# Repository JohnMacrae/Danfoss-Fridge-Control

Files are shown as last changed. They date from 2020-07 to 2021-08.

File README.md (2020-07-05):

# Danfoss-Fridge-Control

I have a Danfoss BD35 and BD50 compressor running the fridge and freezer on my boat. This project has been brewing since I sopke with a friend, Rick, back in 2016 but although I tinkered with it, I didn't get serious - mostly due to lack of confidence born out of lack of competence :)
While we were on board in 2019, however, the mechanical thermostat on the fridge (BD35) broke and I was forced to 'create' something out of what was on board  - an ESP8266, a DS18b20 and a chinesium relay.

It was successful and ran for months without any problems but as you can see it was a bit of a bodge.  So, I decided to make a board and run it on an ESP32.

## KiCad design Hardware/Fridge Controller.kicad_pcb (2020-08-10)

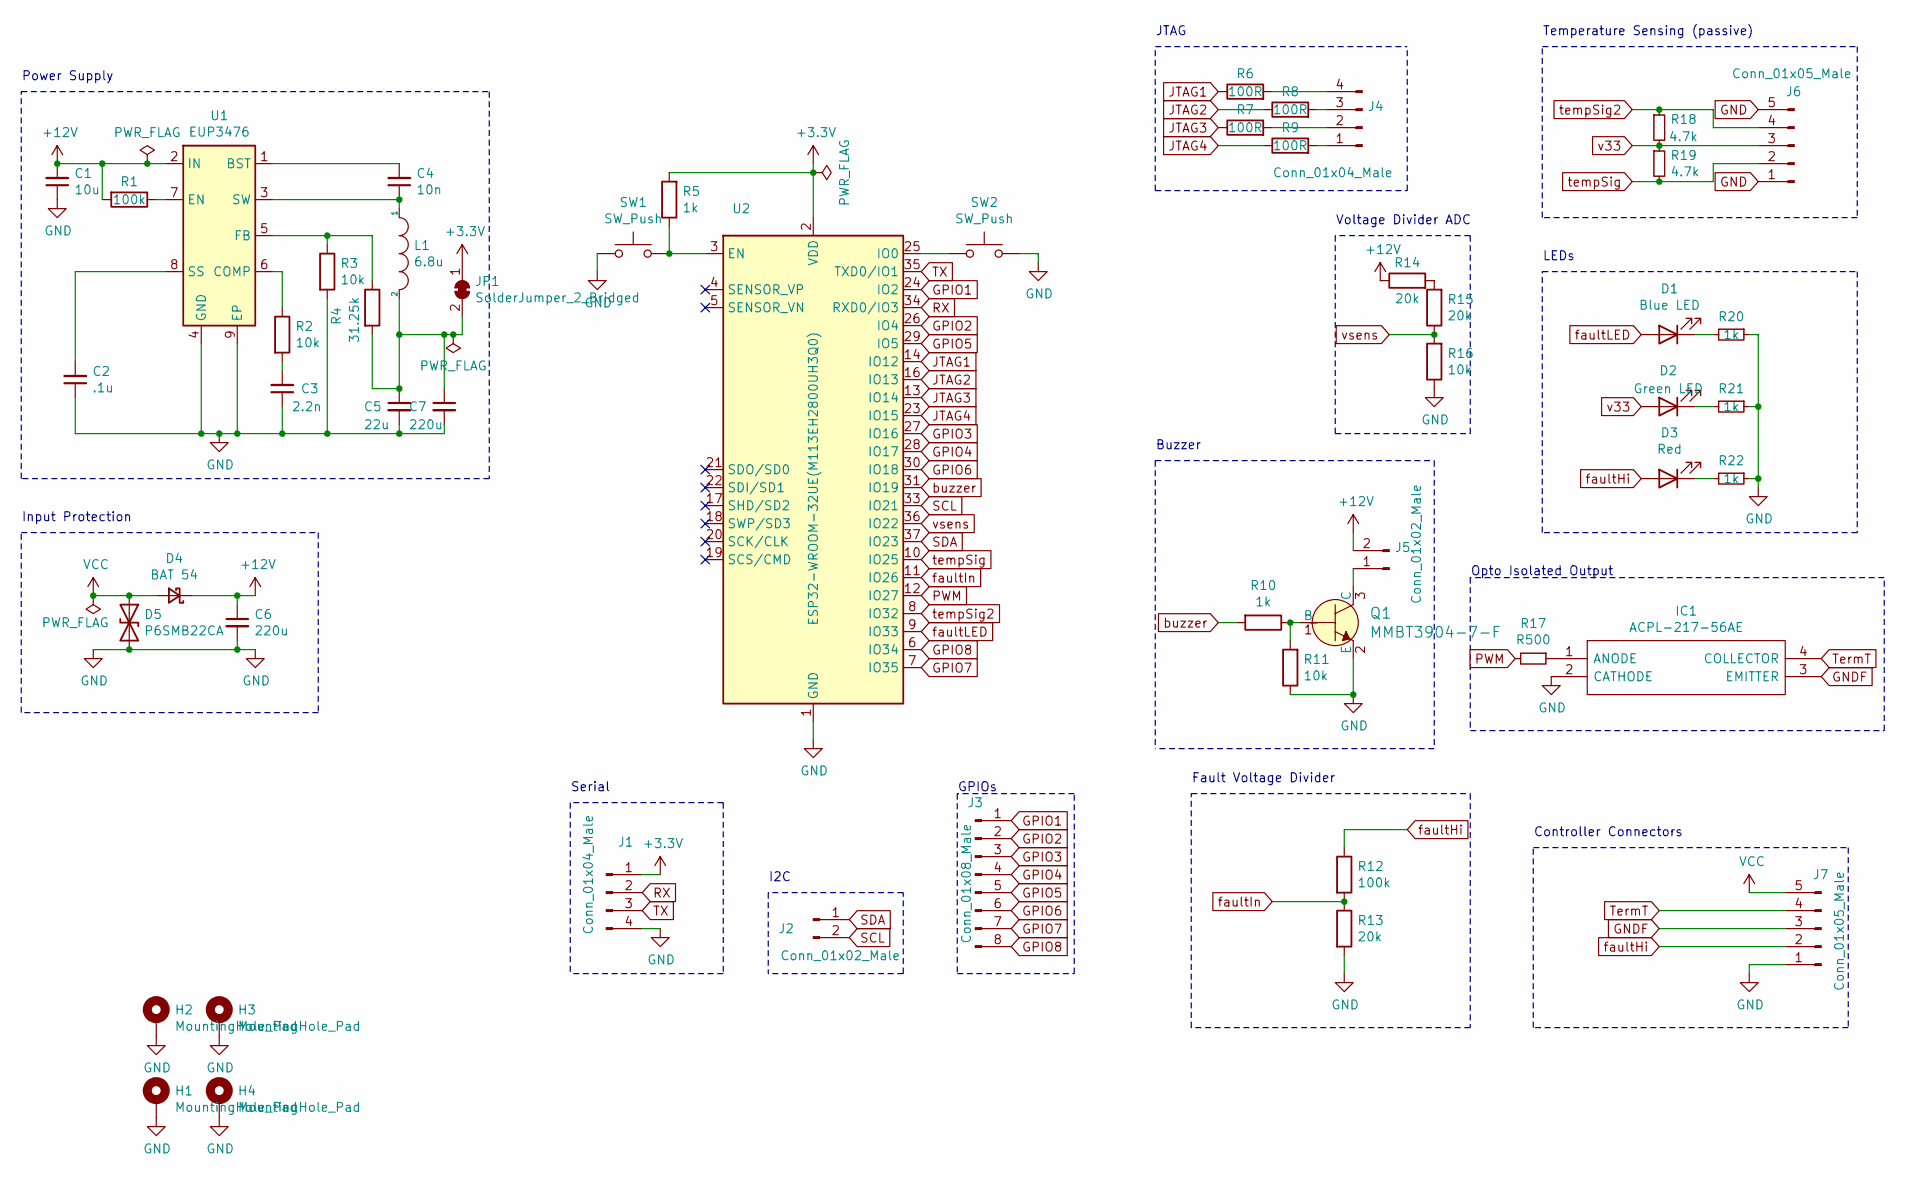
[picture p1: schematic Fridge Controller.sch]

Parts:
C1: 10u; C_0805_2012Metric_Pad1.15x1.40mm_HandSolder
C2: .1u; C_0805_2012Metric_Pad1.15x1.40mm_HandSolder
C3: 2.2n; C_0805_2012Metric_Pad1.15x1.40mm_HandSolder
C4: 10n; C_0805_2012Metric_Pad1.15x1.40mm_HandSolder
C5: 22u; C_0805_2012Metric_Pad1.15x1.40mm_HandSolder
C6: 220u; C_1206_3216Metric_Pad1.42x1.75mm_HandSolder
C7: 220u; CP_EIA-7343-31_Kemet-D_Pad2.25x2.55mm_HandSolder
D1: Blue LED; LED_1206_3216Metric
D2: Green LED; LED_1206_3216Metric
D3: Red; LED_1206_3216Metric
D4: BAT 54; D_SOT-23_ANK
D5: P6SMB22CA; D_SMB
H1, H2, H3, H4: MountingHole_Pad; MountingHole_3.2mm_M3_Pad_Via
IC1: ACPL-217-56AE; SOIC127P700X242-4N; Mouser Part Number 630-ACPL-217-56AE
J1, J4: Conn_01x04_Male; PinHeader_1x04_P2.54mm_Vertical
J2, J5: Conn_01x02_Male; PinHeader_1x02_P2.54mm_Vertical
J3: Conn_01x08_Male; PinHeader_1x08_P2.54mm_Vertical
J6, J7: Conn_01x05_Male; JST_XH_B5B-XH-A_1x05_P2.50mm_Vertical
JP1: SolderJumper_2_Bridged; SolderJumper-2_P1.3mm_Open_Pad1.0x1.5mm
L1: 6.8u; L_Abracon_ASPI-0630LR
Q1: MMBT3904-7-F; SOT-23-3; MPN MMBT3904-7-F; Digi-Key_PN MMBT3904-FDICT-ND
R1, R12: 100k; R_0805_2012Metric_Pad1.15x1.40mm_HandSolder
R2, R3, R11, R16: 10k; R_0805_2012Metric_Pad1.15x1.40mm_HandSolder
R4: 31.25k; R_0805_2012Metric_Pad1.15x1.40mm_HandSolder
R5, R10, R20, R21, R22: 1k; R_0805_2012Metric_Pad1.15x1.40mm_HandSolder
R6, R7, R8, R9: 100R; R_0805_2012Metric_Pad1.15x1.40mm_HandSolder
R13, R14, R15: 20k; R_0805_2012Metric_Pad1.15x1.40mm_HandSolder
R17: R500; R_0805_2012Metric_Pad1.15x1.40mm_HandSolder
R18, R19: 4.7k; R_0805_2012Metric_Pad1.15x1.40mm_HandSolder
SW1, SW2: SW_Push; SW_PUSH_6mm_H5mm
U1: EUP3476; HSOP-8-1EP_3.9x4.9mm_P1.27mm_EP2.41x3.1mm
U2: ESP32-WROOM-32UE(M113EH2800UH3Q0); ESP32-WROOM-32

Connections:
+3V3: J1.1, JP1.1 (A), R5.2, U2.2 (VDD)
+12V: C1.2, C6.1, D4.1 (K), J5.2, R1.2, R14.1, U1.2 (IN)
GND: C1.1, C2.1, C3.1, C5.2, C6.2, C7.2, D5.2 (A2), H1.1, H2.1, H3.1, H4.1, IC1.2 (CATHODE), J1.4, J6.1, J6.5, J7.1, Q1.2 (E), R3.2, R11.1, R13.2, R16.1, R20.1, R21.1, R22.1, SW1.1, SW2.2, U1.4 (GND), U1.9 (EP), U2.1 (GND), U2.15 (GND), U2.38 (GND), U2.39 (GND)
GNDF: IC1.3 (EMITTER), J7.3
GPIO1: J3.1, U2.24 (IO2)
GPIO2: J3.2, U2.26 (IO4)
GPIO3: J3.3, U2.27 (IO16)
GPIO4: J3.4, U2.28 (IO17)
GPIO5: J3.5, U2.29 (IO5)
GPIO6: J3.6, U2.30 (IO18)
GPIO7: J3.7, U2.7 (IO35)
GPIO8: J3.8, U2.6 (IO34)
JTAG1: R6.1, U2.14 (IO12)
JTAG2: R8.1, U2.16 (IO13)
JTAG3: R7.1, U2.13 (IO14)
JTAG4: R9.1, U2.23 (IO15)
unnamed: C2.2, U1.8 (SS)
unnamed: C3.2, R2.2
unnamed: C4.1, L1.1, U1.3 (SW)
unnamed: C4.2, U1.1 (BST)
unnamed: C5.1, C7.1, JP1.2 (B), L1.2, R4.2
unnamed: D1.1 (K), R20.2
unnamed: D2.1 (K), R21.2
unnamed: D3.1 (K), R22.2
unnamed: IC1.1 (ANODE), R17.1
unnamed: J4.1, R9.2
unnamed: J4.2, R7.2
unnamed: J4.3, R8.2
unnamed: J4.4, R6.2
unnamed: J5.1, Q1.3 (C)
unnamed: Q1.1 (B), R10.1, R11.2
unnamed: R1.1, U1.7 (EN)
unnamed: R2.1, U1.6 (COMP)
unnamed: R3.1, R4.1, U1.5 (FB)
unnamed: R5.1, SW1.2, U2.3 (EN)
unnamed: R14.2, R15.2
unnamed: SW2.1, U2.25 (IO0)
PWM: R17.2, U2.12 (IO27)
RX: J1.2, U2.34 (RXD0/IO3)
SCL: J2.2, U2.33 (IO21)
SDA: J2.1, U2.37 (IO23)
TX: J1.3, U2.35 (TXD0/IO1)
TermT: IC1.4 (COLLECTOR), J7.4
VCC: D4.2 (A), D5.1 (A1), J7.5
buzzer: R10.2, U2.31 (IO19)
faultHi: D3.2 (A), J7.2, R12.1
faultIn: R12.2, R13.1, U2.11 (IO26)
faultLED: D1.2 (A), U2.9 (IO33)
tempSig: J6.2, R19.2, U2.10 (IO25)
tempSig2: J6.4, R18.1, U2.8 (IO32)
v33: D2.2 (A), J6.3, R18.2, R19.1
vsens: R15.1, R16.2, U2.36 (IO22)

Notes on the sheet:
Temperature Sensing (passive)
LEDs
Opto Isolated Output
JTAG
Power Supply
Controller Connectors
Fault Voltage Divider
Buzzer
Voltage Divider ADC
GPIOs
Serial
I2C
Input Protection

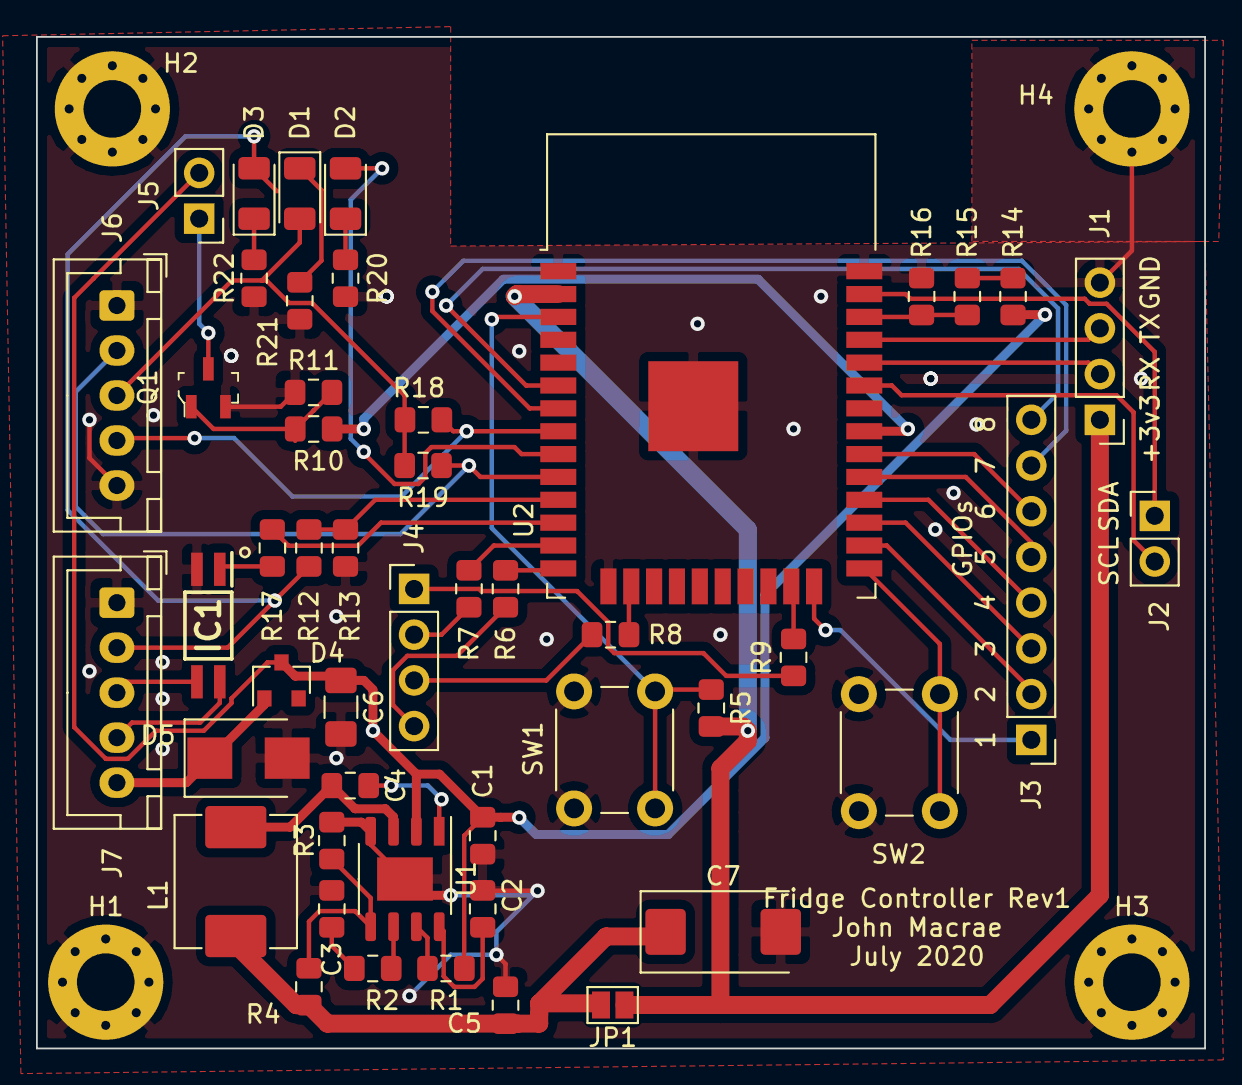
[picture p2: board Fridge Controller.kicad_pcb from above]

Board: 2 copper layers, 64.9 x 56.2 mm, 53 parts (0 on the bottom side), 52 nets.

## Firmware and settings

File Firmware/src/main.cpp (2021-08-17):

#include <Arduino.h>

#include <ArduinoOTA.h>
#include <PubSubClient.h>
#include <ESPmDNS.h>
#include <WiFi.h>
#include <WiFiUdp.h>
#include <ArduinoOTA.h>
#include <FS.h>
#include <SPIFFS.h>
//#include <OneWire.h>
//#include <DallasTemperature.h>
#include "globals.h"
#include "credentials.h"
#include "config.h"
#include "mqtt.h"
#include "pins.h"
#include "pwm.h"
#include "thermoStat.h"
#include "owng.h"
#include "OneWireNg_CurrentPlatform.h"
#include "drivers/DSTherm.h"

//#define RESOLUTION 11
#define OW_PIN 25

// Setup a oneWire instance to communicate with any OneWire devices (not just Maxim/Dallas temperature ICs)
//OneWire oneWire(TEMPSIG);

// Pass our oneWire reference to Dallas Temperature.
//DallasTemperature sensors(&oneWire);

// arrays to hold device address
//DeviceAddress insideThermometer;

/*
 * Set to true for parasitically powered sensors.
 */
#define PARASITE_POWER false

/*
 * Uncomment for power provided by a switching
 * transistor and controlled by this pin.
 */
//#define PWR_CTRL_PIN    9

//static OneWireNg *ow = NULL;
//static DSTherm *dsth = NULL;

volatile int interruptCounter = 0;
int totalInterruptCounter = 0;

struct Fault
{
  uint32_t interval;
  uint16_t code;
  unsigned long fTimerStart;
  bool startTimer;
};

volatile Fault fault = {0, 0, 0, false};

hw_timer_t *timer = NULL;
hw_timer_t *thermoTimer = NULL;

portMUX_TYPE timerMux = portMUX_INITIALIZER_UNLOCKED;

volatile int thermoCounter = 0;

void IRAM_ATTR onThermoTimer()
{
  portENTER_CRITICAL_ISR(&timerMux);

  thermoCounter++;

  portEXIT_CRITICAL_ISR(&timerMux);
}

void IRAM_ATTR onFaultTimer()
{
  portENTER_CRITICAL_ISR(&timerMux);
  /* if (fault.fTimerStart == 0)
  {
    fault.fTimerStart = esp_timer_get_time();
  }
  interruptCounter++;
  */
  portEXIT_CRITICAL_ISR(&timerMux);
}

struct Button
{
  uint32_t numberKeyPresses;
  bool pressed;
};

Button button1 = {0, false};

void IRAM_ATTR isr()
{
  portENTER_CRITICAL_ISR(&timerMux);
  button1.pressed = true;
  portEXIT_CRITICAL_ISR(&timerMux);
}

// function to print a device address
/*void printAddress(DeviceAddress deviceAddress)
{
  for (uint8_t i = 0; i < 8; i++)
  {
    if (deviceAddress[i] < 16)
      Serial.print("0");
    Serial.print(deviceAddress[i], HEX);
  }
}
*/
void OTA_Setup()
{
  ArduinoOTA.setHostname(host);
  ArduinoOTA.onStart([]() { // switch off all the PWMs during upgrade
    SPIFFS.end();
  });

  ArduinoOTA.onEnd([]() { // do a fancy thing with our board led at end

  });

  ArduinoOTA.onError([](ota_error_t error)
                     { ESP.restart(); });

  /* setup the OTA server */
  ArduinoOTA.begin();
}

/*
 * Setup function. Here we do the basics
 */
void setup(void)
{
  // start serial port
  Serial.begin(115200);

  thermoTimer = timerBegin(1, 80, true);
  timerAttachInterrupt(thermoTimer, &onThermoTimer, true);
  timerAlarmWrite(thermoTimer, 10000000, true);
  timerAlarmEnable(thermoTimer);

  setPins();

  pinMode(FAULTIN, INPUT);

  attachInterrupt(FAULTIN, isr, RISING);

  OWsetup();

  fileSystemCheck();
  loadConfig();
  WiFi.mode(WIFI_STA);
  WiFi.begin(Settings.WifiSSID, Settings.WifiKey);

  int count = 0;
  while ((count < 10) && (WiFi.status() != WL_CONNECTED))
  {
    delay(500);
    count++;
    Serial.print(WiFi.status());
    Serial.print(".");
  }
  Serial.println("");

  Serial.println(WiFi.localIP());

  OTA_Setup();

  //sensors.requestTemperatures(); // Send the command to get temperatures
  vTaskDelay(300);
  float tempC = -99;
  //tempC = sensors.getTempC(insideThermometer);
  Serial.println(tempC);

  setupPWM();

  myreconnect();
}

void handleFault()
{
  if (button1.pressed)
  {
    portENTER_CRITICAL(&timerMux);
    button1.pressed = false;
    portEXIT_CRITICAL(&timerMux);

    if (fault.fTimerStart > 0) //Already running counter
    {
      if ((esp_timer_get_time() - fault.fTimerStart) >= 4000000)
      { //end it after 4 s
        fault.fTimerStart = 0;
        Serial.println("Fault reset");
        lasttime = 0;
      }
      else
      {
        if ((esp_timer_get_time() - lasttime) >= 300000)
        {
          fault.code++;
          Serial.printf("Flash %d\n", fault.code);
          lasttime = esp_timer_get_time();
        }
      }
    }
    else
    {
      {
        //Not yet counting
        fault.fTimerStart = esp_timer_get_time(); //Start timer
        fault.code = 1;
        Serial.println("Flash 1");
        lasttime = fault.fTimerStart;
      }
    }
  }
  //Handle fault.code here
}
void handleFaultCode()
{
}

void resetFaultTimer()
{
  if (((esp_timer_get_time() - fault.fTimerStart) >= 4000000) && fault.fTimerStart != 0)
  { //end it after 4 s
    fault.fTimerStart = 0;
    Serial.println("Fault reset");
    if (fault.code > 0)
    {
      handleFaultCode();
    }
  }
}
long lastReconnectAttempt = 0;

boolean reconnect()
{
  if (client.connect(Settings.Host, Settings.ControllerUser, Settings.ControllerPassword))
  {
    // Once connected, publish an announcement...
    client.publish("outTopic", "hello world");
    // ... and resubscribe
    //client.subscribe("inTopic");
  }
  return client.connected();
}
// function to print the temperature for a device
/*
void printTemperature(DeviceAddress deviceAddress)
{
  do
  {
    sensors.requestTemperatures();
    vTaskDelay(750 / (1 << (12 - RESOLUTION)));
    tempC = sensors.getTempCByIndex(0);
  } while ((tempC < -10) || (tempC > 50));

  // get temperature
  //Serial.println();
  if (tempC > -100)
  {
    Serial.print("Temperature: ");
    Serial.println(tempC);

    strcpy(pTopic, "");
    strcat(pTopic, Settings.Host);
    strcat(pTopic, "/tempc");
    snprintf(msg, 63, "%f", tempC);

    myreconnect();

    if (!client.connected())
    {
      long now = millis();
      if (now - lastReconnectAttempt > 5000)
      {
        lastReconnectAttempt = now;
        // Attempt to reconnect
        if (reconnect())
        {
          lastReconnectAttempt = 0;
        }
      }
    }
    if (client.connect(Settings.Host, Settings.ControllerUser, Settings.ControllerPassword))
    {
      client.publish(pTopic, msg);
      
      Serial.print(Settings.Host);
      Serial.print(" : ");
      Serial.print(pTopic);
      Serial.print(" : ");
      Serial.println(msg);
      
    }
  }
}
*/

void runpins()
{
  digitalWrite(BUZZER, LOW);
  vTaskDelay(100);
  digitalWrite(BUZZER, HIGH);
  vTaskDelay(100);
  digitalWrite(BUZZER, LOW);
}

/*
 * Main function. It will request the tempC from the sensors and display on Serial.
 */
void loop(void)
{
  ArduinoOTA.handle();
  client.loop();

  if (thermoCounter > 0)
  {
    portENTER_CRITICAL(&timerMux);
    thermoCounter--;
    portEXIT_CRITICAL(&timerMux);

    do
    {
      OWloop();
    } while ((tempC < -10) && (tempC > 50));

    runled(compSpeed);

    runpins();
  }

  handleFault();

  resetFaultTimer();

  boot = false;
}

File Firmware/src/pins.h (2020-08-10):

#include <Arduino.h>

#define TEMPSIG 21
#define GPIO2 2
#define TX 1
#define RX 3
#define GPIO1 5
#define JTAG1 14
#define JTAG2 16
#define JTAG3 13
#define JTAG4 23
#define GPIO3 16
#define GPIO4 17
#define GPIO5 18
#define GPIO6 19
//#define GPIO7 33 now ow bus
#define VSENS 22
#define SDA 23
#define SCL 25
#define FAULTLED 26
#define FAULTIN 26
#define BUZZER 32
#define PWM 33
#define TEMPSIG2 35

void setPins()
{
    pinMode(FAULTLED, OUTPUT);
    digitalWrite(FAULTLED, LOW);

    pinMode(PWM, OUTPUT);
    digitalWrite(PWM, HIGH);

    pinMode(BUZZER, OUTPUT);
    digitalWrite(BUZZER, LOW);

    pinMode(VSENS, INPUT);
    pinMode(FAULTIN, INPUT);

pinMode(TEMPSIG, OUTPUT);

}

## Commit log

2020-06-30 PWM working
2020-07-05 Fixed temperature measurement
2020-08-06 Fixed temperature measurement and buzzer circuit tested
    [globals.h, main.cpp, pins.h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]
2020-08-10 Added Hardware
    [Fridge Controller.kicad_pcb, Fridge Controller.sch]
